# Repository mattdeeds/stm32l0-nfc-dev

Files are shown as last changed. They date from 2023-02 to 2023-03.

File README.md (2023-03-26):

# `STM32L0 Based Dynamic NFC Tag in Rust`

> Uses [rust-stm32l010f4px-template](https://github.com/mattdeeds/rust-stm32l010f4px-template)

## WIP

Test program blinks LED based off of readings from TMP102 temp sensor.

Currently working on ST25DV integration.

Hardware folder contains Eagle schematic/board files and finished board images.

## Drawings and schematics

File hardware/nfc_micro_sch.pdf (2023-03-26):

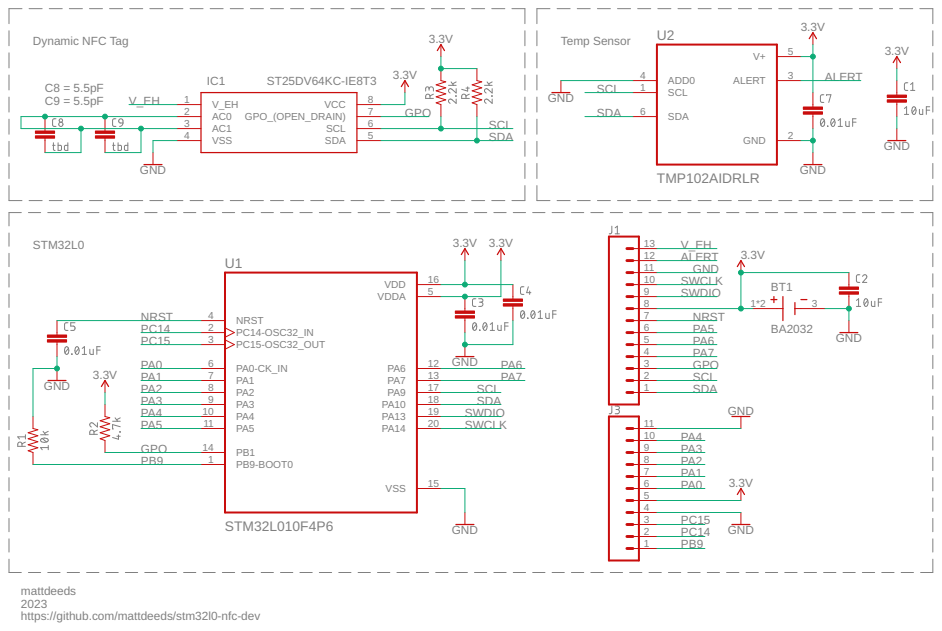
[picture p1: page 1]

4 | | 5 | SDA

mattdeeds
https://github.com/mattdeeds/stm32l0-nfc-dev

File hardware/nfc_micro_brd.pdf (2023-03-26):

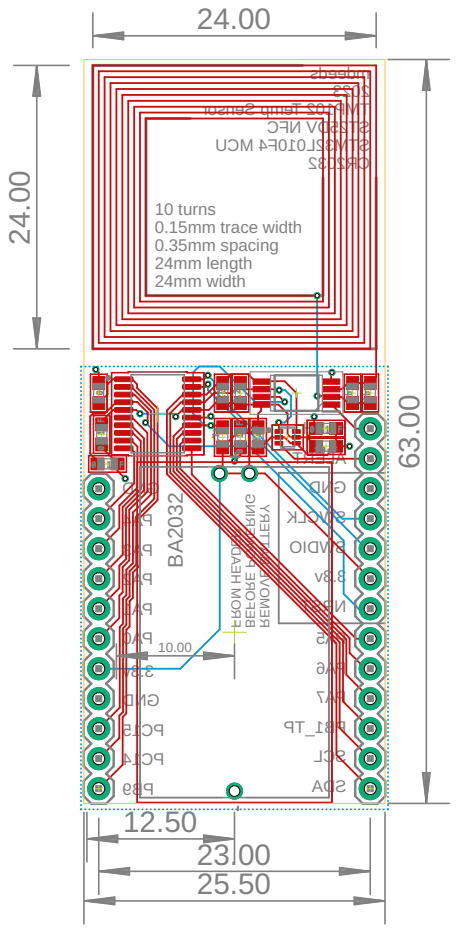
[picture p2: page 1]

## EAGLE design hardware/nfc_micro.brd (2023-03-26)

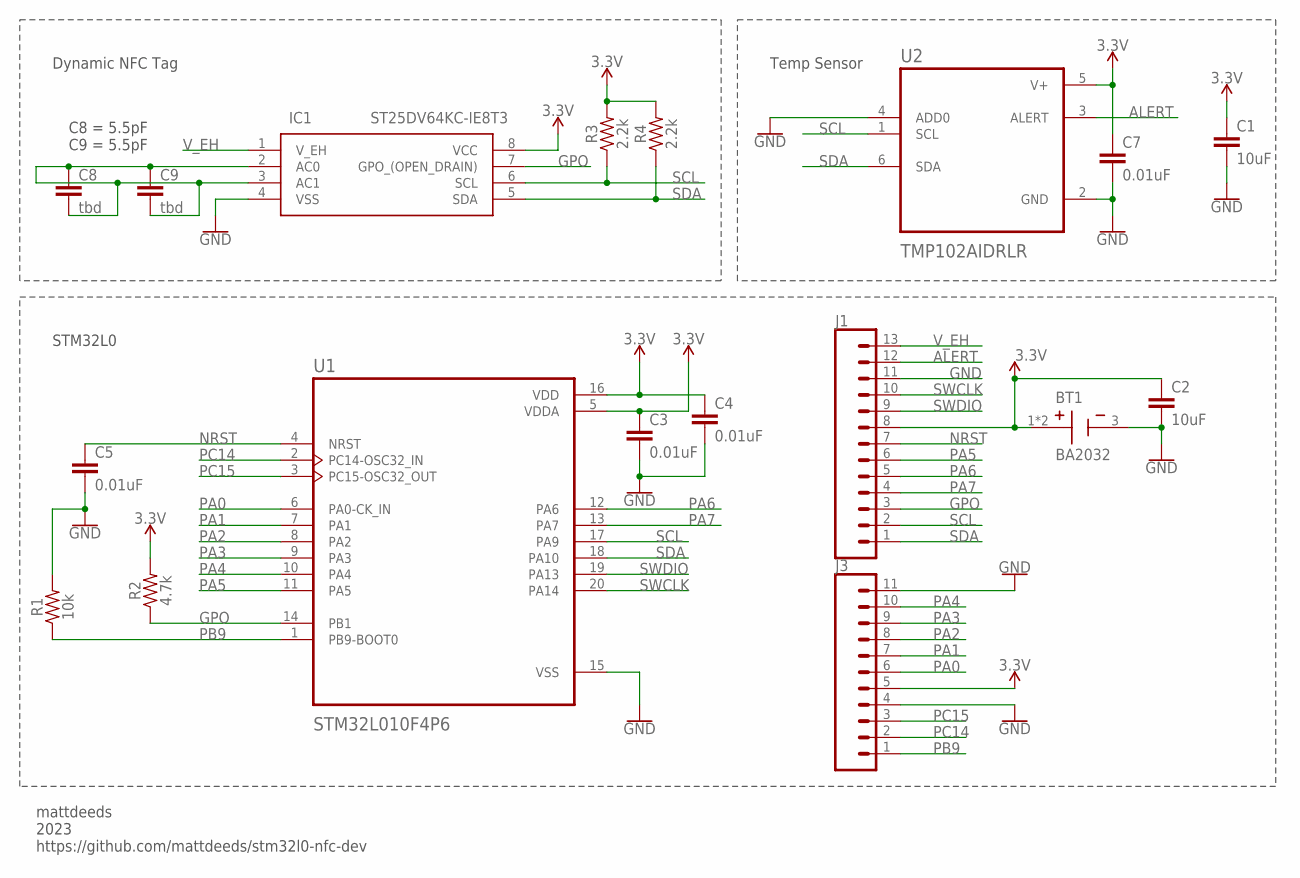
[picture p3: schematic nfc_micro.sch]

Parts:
BT1: BA2032; BAT_BA2032
C1, C2: 10uF; 0603
C3, C4, C5, C7: 0.01uF; 0603
C8, C9: tbd; 0603
IC1: ST25DV64KC-IE8T3; SOP65P640X120-8N
J1: CONN_13; 1X13
J3: CONN_11; 1X11
R1: 10k; 0603
R2: 4.7k; 0603
R3, R4: 2.2k; 0603
U1: STM32L010F4P6; SOP65P640X120-20N
U2: TMP102AIDRLR; SOT50P160X60-6N

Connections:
3.3V: BT1.1 (+), BT1.2 (+), C1.1, C2.1, C3.1, C4.1, C7.1, IC1.8 (VCC), J1.8, J3.5, R2.2, R3.2, R4.2, U1.5 (VDDA), U1.16 (VDD), U2.5 (V+)
ALERT: J1.12, U2.3 (ALERT)
GND: BT1.3 (-), C1.2, C2.2, C3.2, C4.2, C5.2, C7.2, IC1.4 (VSS), J1.11, J3.4, J3.11, R1.2, U1.15 (VSS), U2.2 (GND), U2.4 (ADD0)
GPO: IC1.7 (GPO_(OPEN_DRAIN)), J1.3, R2.1, U1.14 (PB1)
unnamed: C8.1, C8.2, C9.1, C9.2, IC1.2 (AC0), IC1.3 (AC1)
NRST: C5.1, J1.7, U1.4 (NRST)
PA0: J3.6, U1.6 (PA0-CK_IN)
PA1: J3.7, U1.7 (PA1)
PA2: J3.8, U1.8 (PA2)
PA3: J3.9, U1.9 (PA3)
PA4: J3.10, U1.10 (PA4)
PA5: J1.6, U1.11 (PA5)
PA6: J1.5, U1.12 (PA6)
PA7: J1.4, U1.13 (PA7)
PB9: J3.1, R1.1, U1.1 (PB9-BOOT0)
PC14: J3.2, U1.2 (PC14-OSC32_IN)
PC15: J3.3, U1.3 (PC15-OSC32_OUT)
SCL: IC1.6 (SCL), J1.2, R3.1, U1.17 (PA9), U2.1 (SCL)
SDA: IC1.5 (SDA), J1.1, R4.1, U1.18 (PA10), U2.6 (SDA)
SWCLK: J1.10, U1.20 (PA14)
SWDIO: J1.9, U1.19 (PA13)
V_EH: IC1.1 (V_EH), J1.13

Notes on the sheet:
Temp Sensor
Dynamic NFC Tag
STM32L0
C8 = 5.5pF C9 = 5.5pF
mattdeeds 2023 https://github.com/mattdeeds/stm32l0-nfc-dev

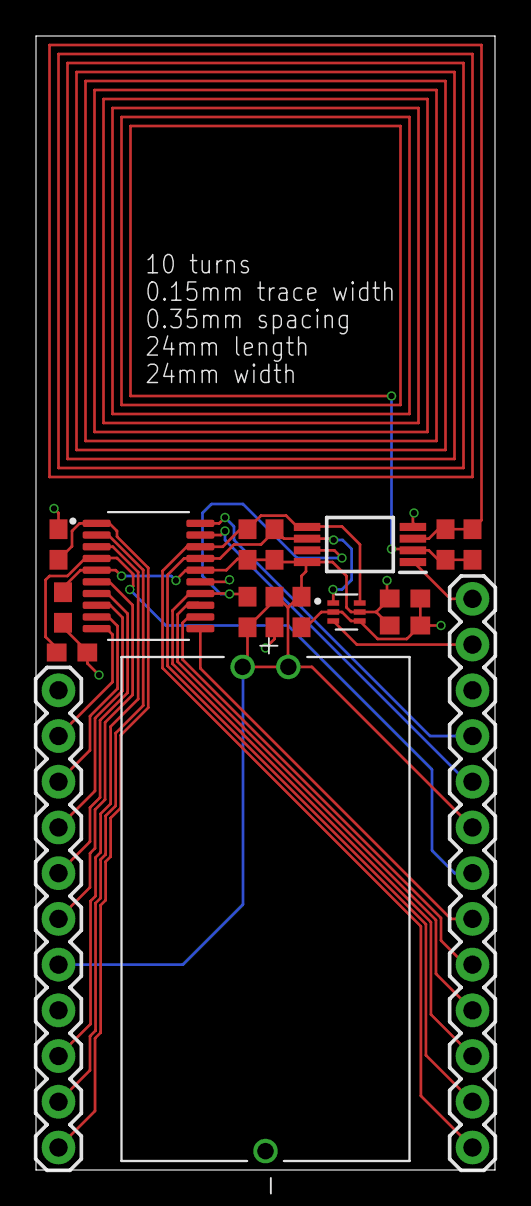
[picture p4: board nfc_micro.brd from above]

Board: 2 copper layers, 25.5 x 63.0 mm, 18 parts (0 on the bottom side), 22 nets.

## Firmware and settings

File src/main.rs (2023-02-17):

#![deny(warnings)]
#![deny(unsafe_code)]
#![no_main]
#![no_std]

extern crate panic_halt;

use cortex_m::asm::delay;
use cortex_m_rt::entry;
use stm32l0xx_hal::{pac, prelude::*, rcc::Config};
use tmp1x2::{Tmp1x2, SlaveAddr};
use embedded_time::rate::*;

#[entry]
fn main() -> ! {
    let dp = pac::Peripherals::take().unwrap();

    // Configure the clock.
    let mut rcc = dp.RCC.freeze(Config::hsi16());

    // Acquire the GPIOA peripheral. This also enables the clock for GPIOA in
    // the RCC register.
    let gpioa = dp.GPIOA.split(&mut rcc);

    // Configure PA1 as output for led
    let mut led = gpioa.pa7.into_push_pull_output();

    // configure I2C pins
    let sda = gpioa.pa10.into_open_drain_output();
    let scl = gpioa.pa9.into_open_drain_output();

    let i2c = dp.I2C1.i2c(sda, scl, Hertz(100_000), &mut rcc);
    let address = SlaveAddr::default();
    let mut sensor = Tmp1x2::new(i2c, address);

    loop {
        
        let temperature = sensor.read_temperature().unwrap();
        let delay_time;

        // Set delay time based on temperature
        // if temperature > 22.0 then fast blink else slow blink
        // temp should be over 22.0 in house

        if temperature > 22.0 {
            delay_time = 4000000;
        } else {
            delay_time = 20000000;
        }

        led.set_high().unwrap();
        delay(delay_time);

        led.set_low().unwrap();
        delay(delay_time);
    }
}

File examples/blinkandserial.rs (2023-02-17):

#![deny(warnings)]
#![deny(unsafe_code)]
#![no_main]
#![no_std]

extern crate panic_halt;

use core::fmt::Write;
use cortex_m_rt::entry;
use stm32l0xx_hal::{pac, prelude::*, rcc::Config, serial};

// use nb::block;

// blink and serial write example

#[entry]
fn main() -> ! {
    let dp = pac::Peripherals::take().unwrap();
    let cp = cortex_m::Peripherals::take().unwrap();

    // Configure the clock.
    let mut rcc = dp.RCC.freeze(Config::hsi16());

    // Acquire the GPIOA peripheral. This also enables the clock for GPIOA in
    // the RCC register.
    let gpioa = dp.GPIOA.split(&mut rcc);

    // Configure PA1 as output.
    let mut led = gpioa.pa7.into_push_pull_output();

    // Choose TX / RX pins
    let tx_pin = gpioa.pa2;
    let rx_pin = gpioa.pa3;

    // Configure the serial peripheral.
    let serial = dp
        .USART2
        .usart(tx_pin, rx_pin, serial::Config::default(), &mut rcc)
        .unwrap();

    let (mut tx, _rx) = serial.split();

    // Get the delay provider.
    let mut delay = cp.SYST.delay(rcc.clocks);

    // core::fmt::Write is implemented for tx.
    //writeln!(tx, "Hello, world!").unwrap();

    loop {
        writeln!(tx, "Hello, world!").unwrap();
        
        led.set_high().unwrap();
        delay.delay_ms(1000_u16);

        led.set_low().unwrap();
        delay.delay_ms(1000_u16);
    }
}

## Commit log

2023-02-17 init
    temp sensor working
2023-03-26 add hardware files
    [nfc_micro.brd, nfc_micro.sch]

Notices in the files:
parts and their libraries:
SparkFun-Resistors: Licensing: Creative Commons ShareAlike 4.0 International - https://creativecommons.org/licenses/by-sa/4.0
